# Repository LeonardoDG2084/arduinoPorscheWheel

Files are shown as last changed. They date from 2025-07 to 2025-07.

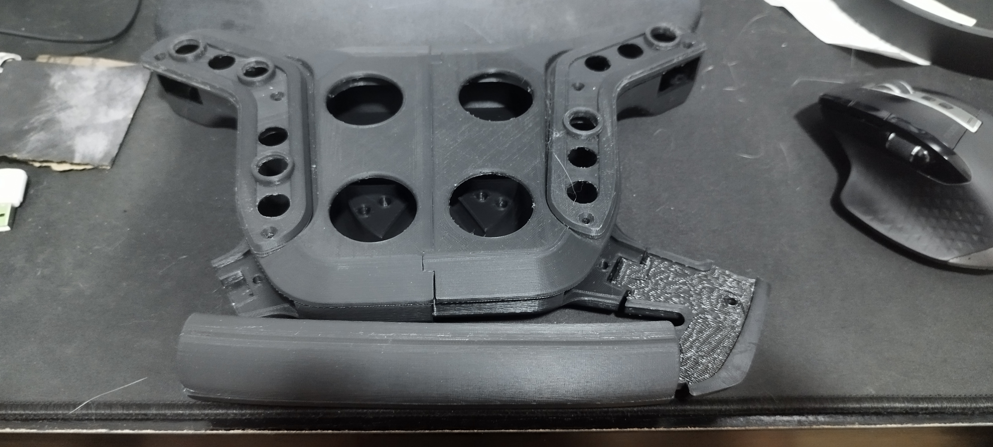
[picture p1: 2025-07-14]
imgs/IMG_20241227_091950.jpg

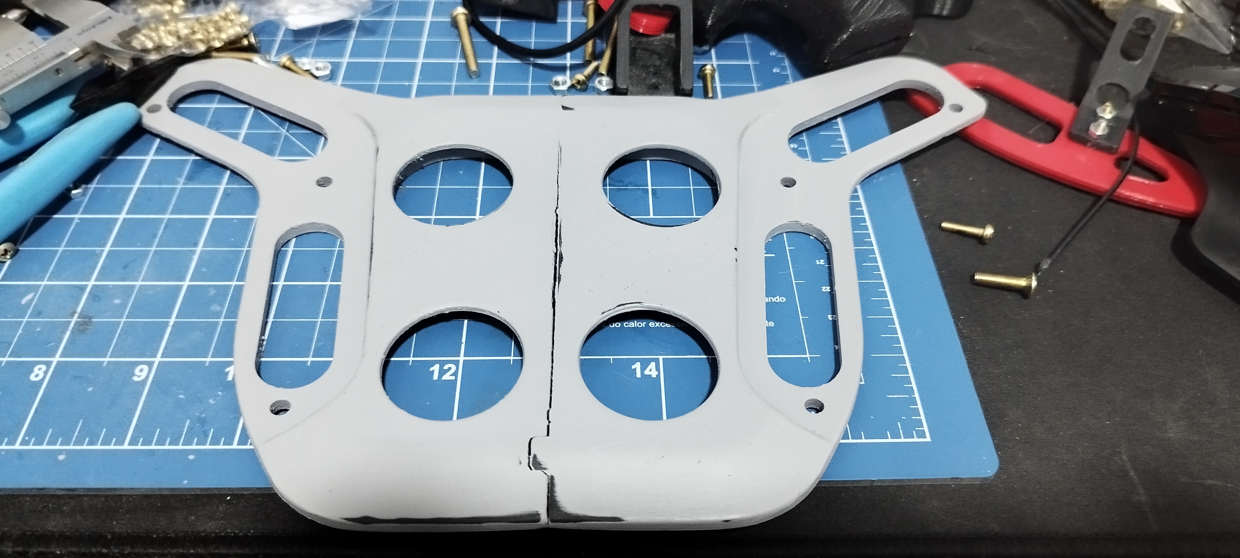
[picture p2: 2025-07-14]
imgs/IMG_20250108_130740.jpg

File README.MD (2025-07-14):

# Introdução

Esse repositorio foi criado para quem deseja reproduzir o projeto de volante do porsche 992 hospedado nesse !(link)https://www.printables.com/model/337684-turn-911-gt3-r-2023-diy-sim-racing-steering-wheel, ao criar esse volante algumas coisas não estavam 100% presentes e também o link do discord para tirar duvidas parece que foi desativado, outra dificuldade foi não ir pelo caminho de mandar fazer a PCB, o que iria encaresser demais o valor do volante, que no momento que fiz gastei em torno de R$500,00. Para esse projeto é necessario uma impressora 3d e algumas ferramentas que vou listar aqui, então antes de decidir reproduzir esse volante verifique se consiga ter acesso a ferramentas e componentes que serão necessários.

Esse foi o primeiro volante que fiz e também primeiro contato com muita das coisas que precisei fazer como pintura, eletronica, arduino, etc, Logo você pode identificar algumas decisões erradas empregadas aqui, se tiver algo a acrescentar faça um comentario ou issue ou PR, se tiver familiarizado com o GitHUB.

Diferenças entre o projeto original e o que acabei fazendo, no lugar dos rotacionadores centrais que possuem posições especificas eu optei por utilizar encoders rotativos comuns o que faz reduzir as opções de configurações, mas o volante acabou ficando com 26 botões, acredito que seja o suficiente para configurar tudo durante a corrida. Volante não possui quaisquer LED, prefiri dar prioridade aos botões.

# Caracteristicas do volante

- 2 - Paddle Switchs
- 1 - Embreagem (potenciomento)
- 14 - Botões (12 Frontais e 2 Traseiros)
- 5 - Encoders rotativos 
- 1 - Joystick Analogico

# Materiais e Valores

 - Fusion360
    - Licença para uso pessoal.
- Impressora 3d 
 - Utilizei uma Ender 3 V1 com bico de 0.4 e 1Kg de filamento de qualquer cor eu utilizei PLA (R$100,00)
 - Uma chapa de aluminio de 3mm 20x30cm (R$35,00)
    - Serra tico-tico
    - Laminas para aluminio que cortem aluminio de 3m possam fazer contorno. 
    - Sugestão de serras: Bosh T118EOF ou Starrett BU214S (R$50,00)
- Lixas (150,250, 400 e 600) (R$10,00)
- Spray 
    - Primer (R$25,00)
    - Preto (R$25,00)
    - Cinza Metalico (R$25,00)
    - Verniz (R$25,00)
- Parafusos e Porcas
  - M3 (R$5,00)
  - M4 (R$5,00)
- Switchs (R$10,00)
- Insert metalico de rosca
    - M3 (R$30,00)
    - M4 (R$30,00)
- Botões
    - Tactil de 12mm (R$30,00)
- Arduino Pro micro (R$50,00)
- Imã 
    - 10x3mm (R$25,00)
- Encoders Rotativos (R$20,00)
- Potenciomento 10k (R$3,00)
- Multiplexador 16 canais CD74HC4067 (R$20,00)
- Cabos Jumpers para prototipo e euilização posterior. (R$30,00)
- Ferro de Solda (R$60,00)
- Estanho (R$15,00)
- Joystick Analogico para arduino (R$20,00)
- Cabo USB micro espiral
- Plugue macho e femea GX2 de 4 vias (R$13,00)
- Multimetro 

# Impressão 3d

Não tem muito segredo para a impressão 3d, a orientação das peças estão presentes no PDF dentro desse repositorio, unica dica é referente a altura da camada, se o seu fatiador possuir a funcionalidade de altura variavel, reduza a altura da camada em lugares curvos para reduzir o tempo de lixamento, é melhor a impressora trabalhar do que você!.

# Aro em Aço (Opicional)

# Lixamento e Pintura

# Soldagem

# Eletronica

Nesse projeto utilizei todas as portas do Arduino e foi necessário um multiplexador para conseguir colocar os 26 botões.
O esquema de Fios estão presentes nesse repositorio.

# Embreagem

No projeto não da detalhes de como fazer a embreagem, então recorri a um pojeto de embreagem pronto e adaptei ao furo do volante, os arquivos podem ser encontrados nesse repositorio

# Joystick Analogico

# Knobs

Os knobs utilizados nesse projeto originalmente achei pequenos e acabei optando por fazer novos utilizando esse projeto: !(link)https://www.printables.com/model/580299-ultimate-diy-replacement-knob-pack-for-samsung-sme/files

Acabei utilizando o modelo 7, para editar ele de acordo com as dimensões do furo você vai precisar do Fusion360, nesse !(video)https://www.youtube.com/watch?v=VST1j0NKjeQ ele mostra como, nele vc consegue dimensionar para caber nos furos da tampa do volante.

# Montagem

# Grips (empunhaduras)

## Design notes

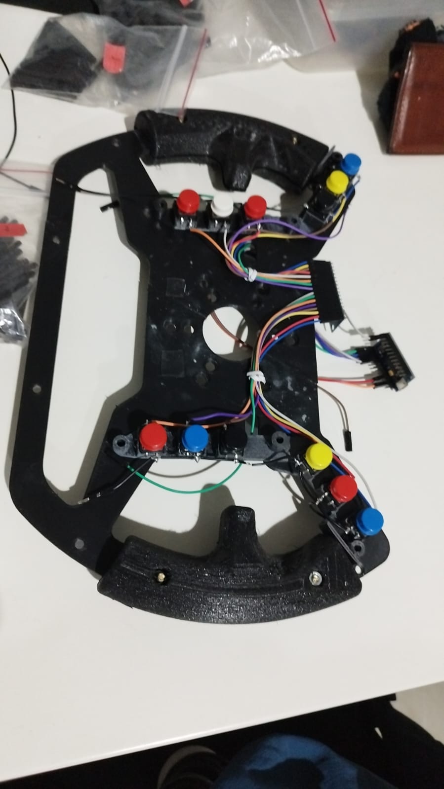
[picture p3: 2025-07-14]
imgs/Imagem do WhatsApp de 2025-01-16 à(s) 18.56.38_65e9340a.jpg

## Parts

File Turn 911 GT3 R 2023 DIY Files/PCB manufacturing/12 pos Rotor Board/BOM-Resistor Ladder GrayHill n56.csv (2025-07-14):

Comment | Designator | Footprint | LCSC
R_Small | R1,R10,R11,R2,R3,R4,R5,R6,R7,R8,R9 | R_0402_1005Metric | C11702

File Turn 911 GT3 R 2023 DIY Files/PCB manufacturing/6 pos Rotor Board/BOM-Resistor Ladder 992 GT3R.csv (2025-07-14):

Comment | Designator | Footprint | LCSC
R_Small | R12,R13,R14,R15,R16,R17,R18 | R_0402_1005Metric | C11702

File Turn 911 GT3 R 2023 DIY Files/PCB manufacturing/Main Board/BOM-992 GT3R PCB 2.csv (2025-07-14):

Comment | Designator | Footprint | LCSC
LED | D1,D10,D11,D12,D13,D14,D15,D16,D17,D18,D19,D2,D20,D21,D22,D23,D24,D25,D26,D27,D28,D29,D3,D30,D31,D32,D33,D34,D35,D36,D37,D38,D39,D4,D40,D41,D42,D43,D44,D45,D46,D47,D48,D49,D5,D50,D51,D52,D6,D7,D8,D9 | LED_0805_2012Metric | C110099
10NF | C1,C2,C3,C4 | C_0805_2012Metric | C1710

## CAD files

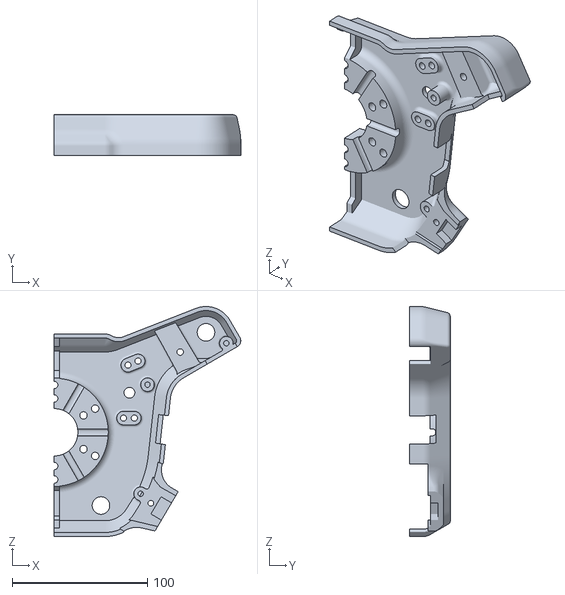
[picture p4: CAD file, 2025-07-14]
Turn 911 GT3 R 2023 DIY Files/3D Pritning/FDM Pritning/Main Shell Right.stl
138.1 x 30.0 x 170.3

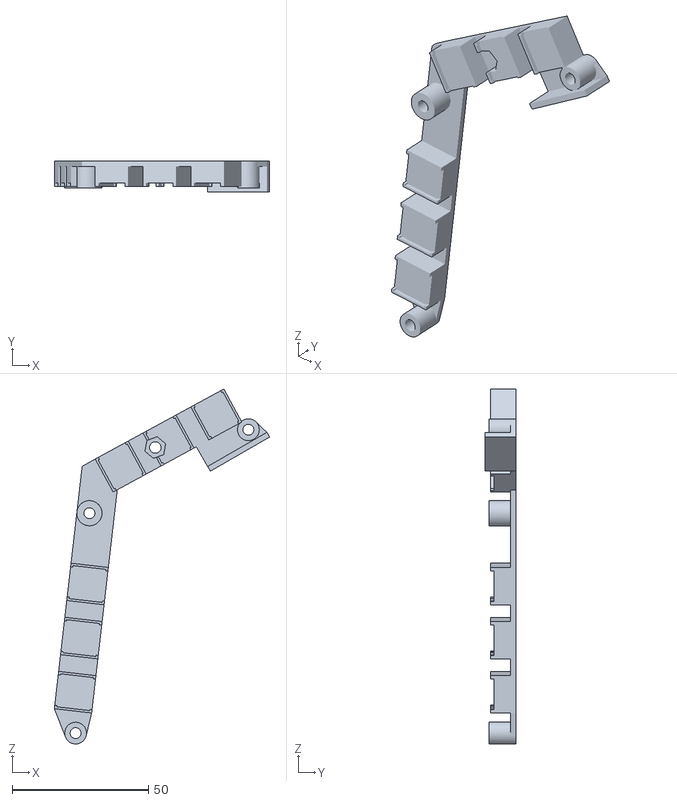
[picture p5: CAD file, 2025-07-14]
custom/NonPCB-button-holder-right.stl
79.1 x 11.5 x 130.4

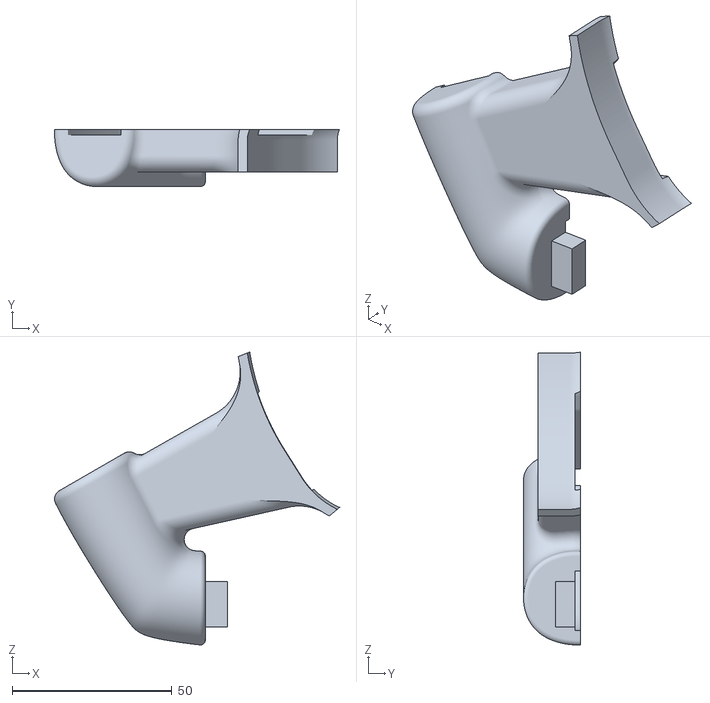
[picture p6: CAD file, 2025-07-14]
Turn 911 GT3 R 2023 DIY Files/3D Pritning/3D Printing Service/PA-12 Nylon/Front handel Left MJF.stl
89.1 x 17.8 x 91.6

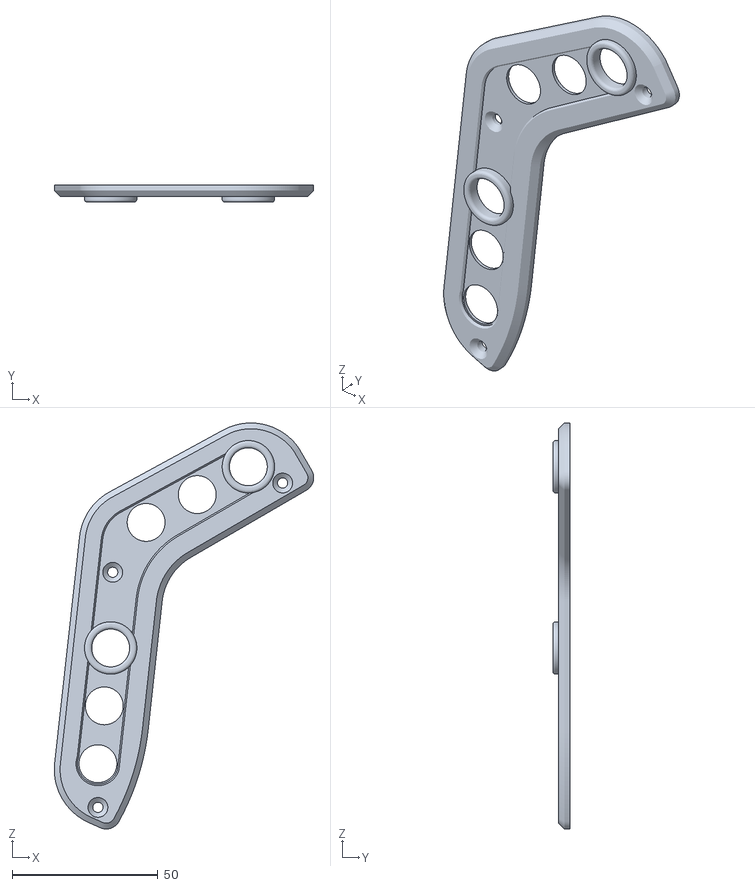
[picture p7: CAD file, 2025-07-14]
Turn 911 GT3 R 2023 DIY Files/3D Pritning/3D Printing Service/Resin Black/Button Guard Right.stl
89.1 x 6.00 x 139.5

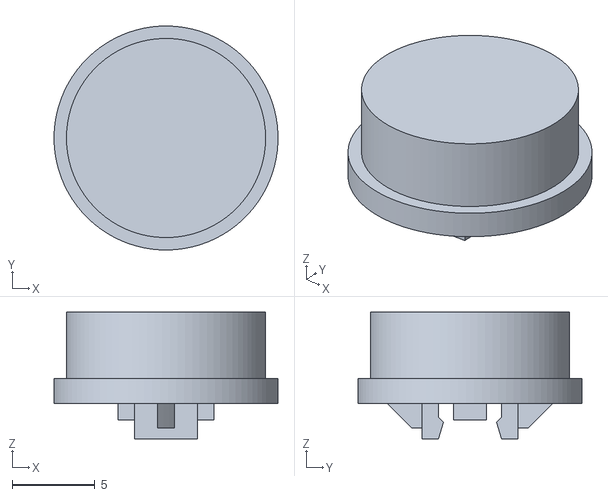
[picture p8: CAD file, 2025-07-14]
Turn 911 GT3 R 2023 DIY Files/3D Pritning/3D Printing Service/Resin White/Button Cap 12mm.stl
13.5 x 13.5 x 7.65

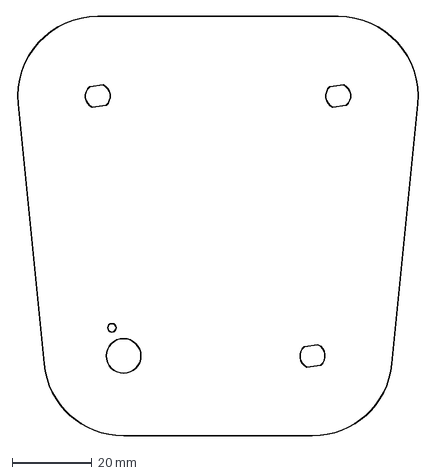
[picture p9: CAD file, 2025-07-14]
Turn 911 GT3 R 2023 DIY Files/Acrylic Sheet/Acrylic Sheet DXF.dxf
101.1 x 105.1 mm

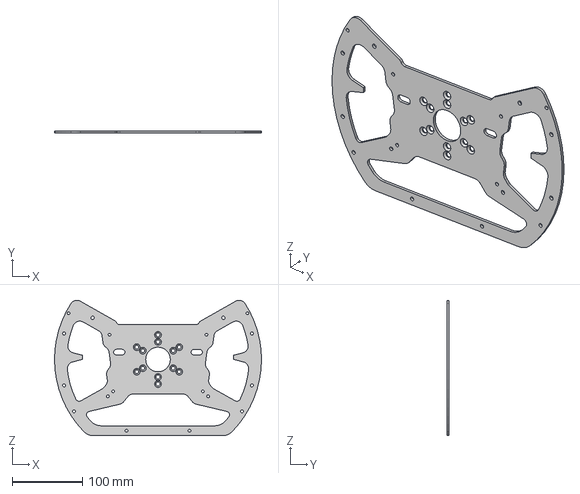
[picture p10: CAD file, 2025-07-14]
Turn 911 GT3 R 2023 DIY Files/Core Plate and Shifters/Core Plate.step
295.0 x 3.00 x 193.0 mm

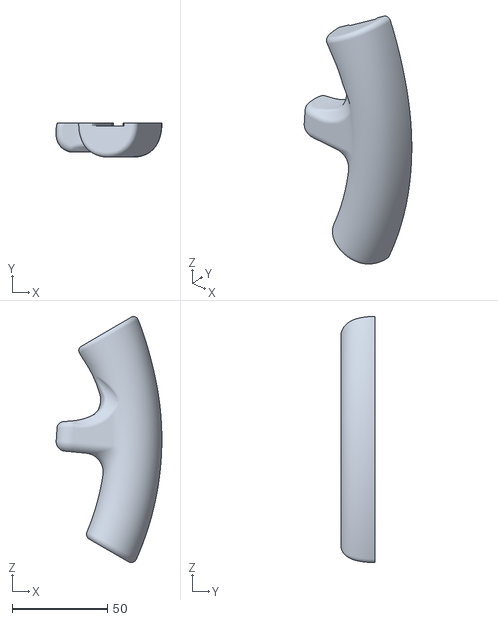
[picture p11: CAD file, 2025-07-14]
Turn 911 GT3 R 2023 DIY Files/Grips/Insert Grips Softtuch/Right Front grip Inserts Softtuch.stl
55.4 x 18.0 x 128.9

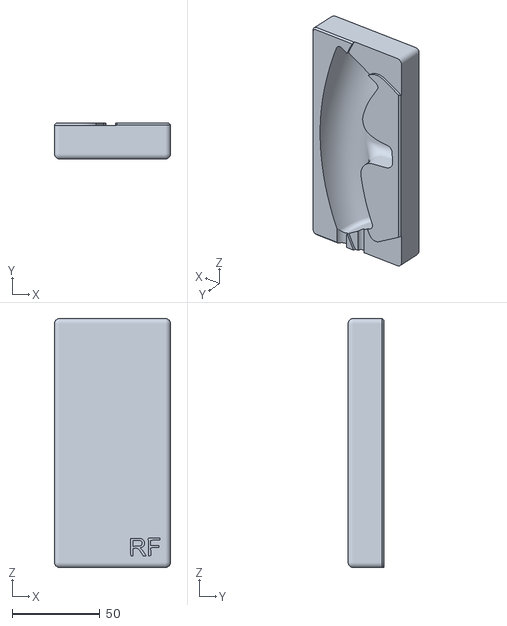
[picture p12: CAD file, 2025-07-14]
Turn 911 GT3 R 2023 DIY Files/Grips/Molded Grips/RF Mold.stl
66.3 x 20.5 x 142.1

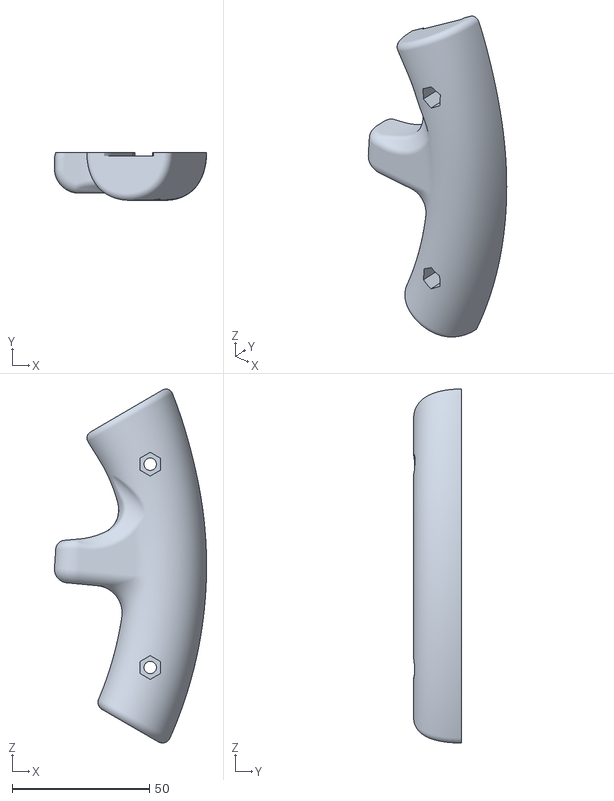
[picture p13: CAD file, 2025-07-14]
Turn 911 GT3 R 2023 DIY Files/Grips/Printed Gap/Grip Gap Right Front.stl
55.4 x 17.3 x 128.8

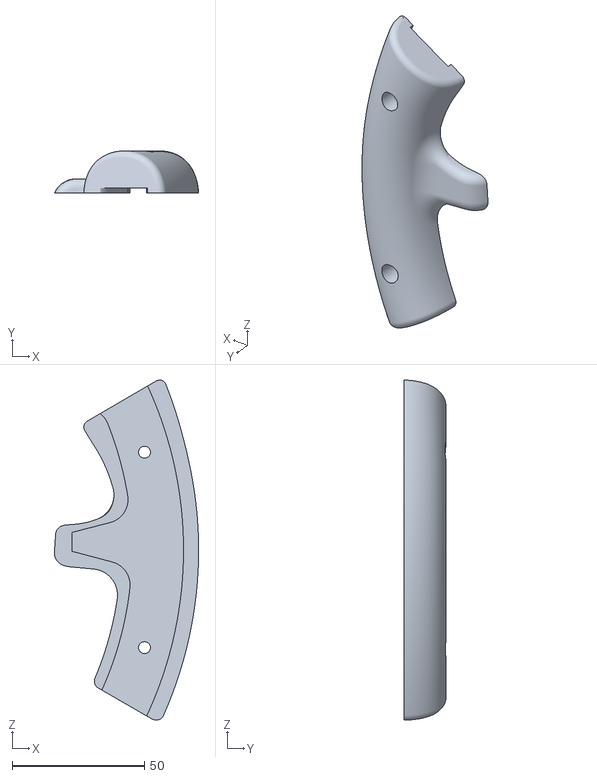
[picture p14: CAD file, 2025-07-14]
Turn 911 GT3 R 2023 DIY Files/Grips/Printed No Cap/Grip NoGap Right Back.stl
54.6 x 16.0 x 128.7

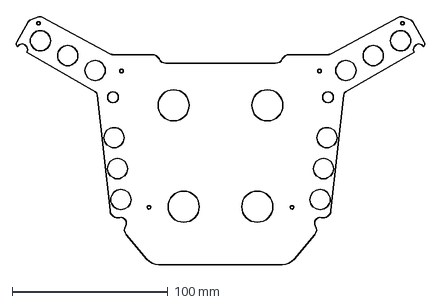
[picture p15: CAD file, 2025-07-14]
Turn 911 GT3 R 2023 DIY Files/PCB Files KiCad/PCB outline.dxf
262.6 x 159.4 mm

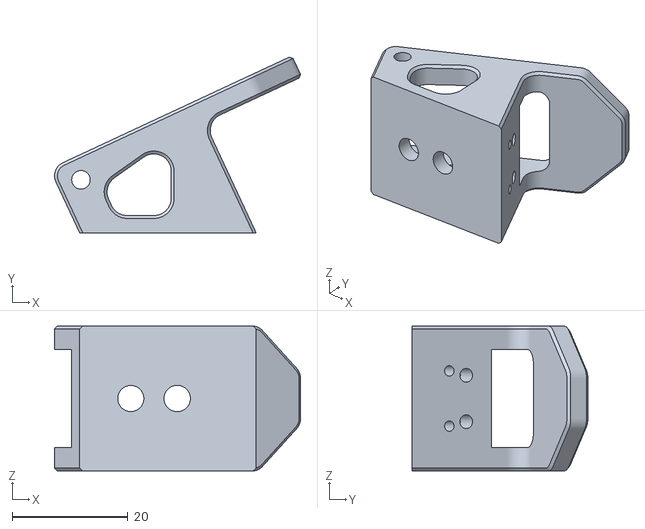
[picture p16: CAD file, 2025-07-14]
Turn 911 GT3 R 2023 DIY Files/Shifters/3D Pritning/Shifter Body v2_4p.stl
42.5 x 30.3 x 25.0

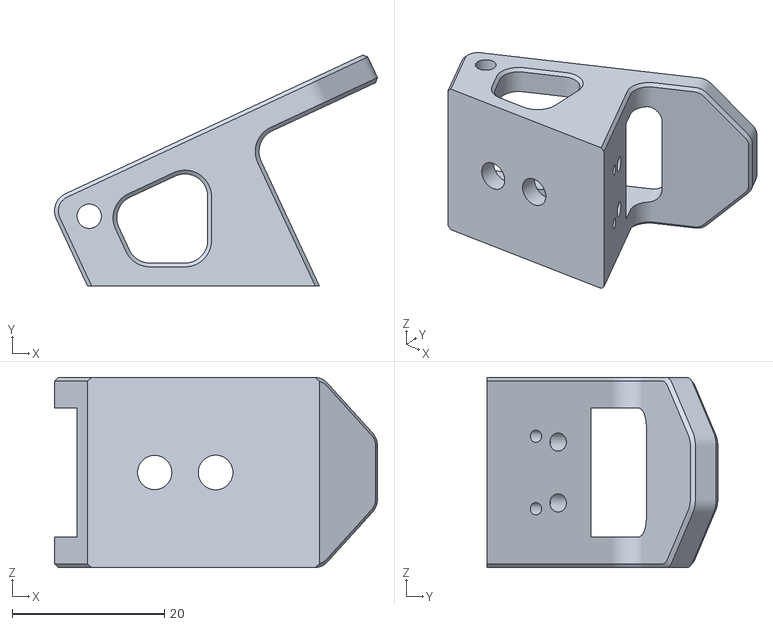
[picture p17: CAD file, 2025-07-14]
Turn 911 GT3 R 2023 DIY Files/Shifters/CNC/Shifter Body V2_3c.stl
42.5 x 30.3 x 25.0

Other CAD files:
Turn 911 GT3 R 2023 DIY Files/3D Pritning/FDM Pritning/Main Shell Left.stl
custom/top-knobs-and-joystick.stl
Turn 911 GT3 R 2023 DIY Files/3D Pritning/3D Printing Service/PA-12 Nylon/Handel Mid Front MJF.stl
Turn 911 GT3 R 2023 DIY Files/3D Pritning/3D Printing Service/Resin Black/Thumb Rotor.stl
Turn 911 GT3 R 2023 DIY Files/3D Pritning/3D Printing Service/PA-12 Nylon/Front Lid MJF.stl
Turn 911 GT3 R 2023 DIY Files/3D Pritning/3D Printing Service/PA-12 Nylon/Front handel Right MJF.stl
Turn 911 GT3 R 2023 DIY Files/3D Pritning/3D Printing Service/PA-12 Nylon/Handel Mid Back MJF.stl
Turn 911 GT3 R 2023 DIY Files/3D Pritning/3D Printing Service/Resin Black/12p Rotor Knob.stl
Turn 911 GT3 R 2023 DIY Files/3D Pritning/3D Printing Service/Resin Black/6p Rotor Knob.stl
Turn 911 GT3 R 2023 DIY Files/3D Pritning/3D Printing Service/Resin Black/Button Guard Left.stl
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

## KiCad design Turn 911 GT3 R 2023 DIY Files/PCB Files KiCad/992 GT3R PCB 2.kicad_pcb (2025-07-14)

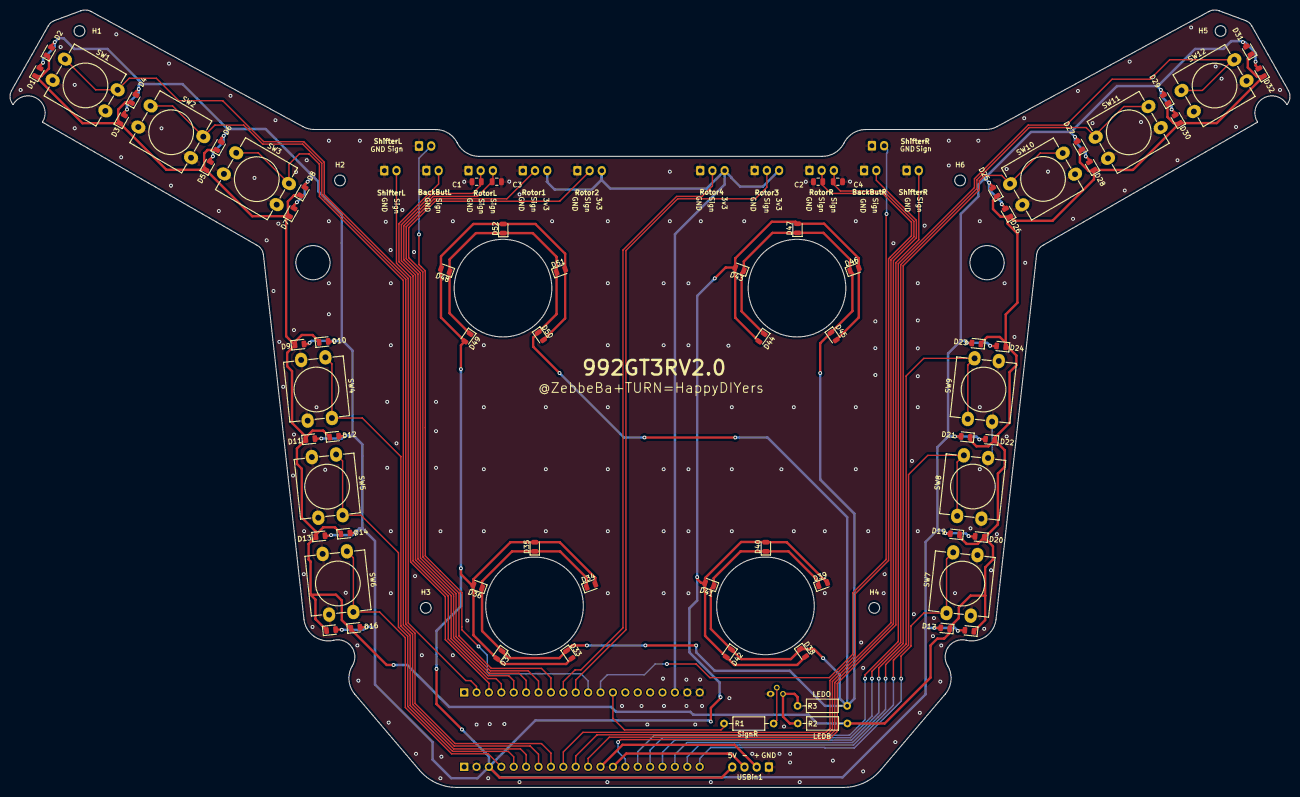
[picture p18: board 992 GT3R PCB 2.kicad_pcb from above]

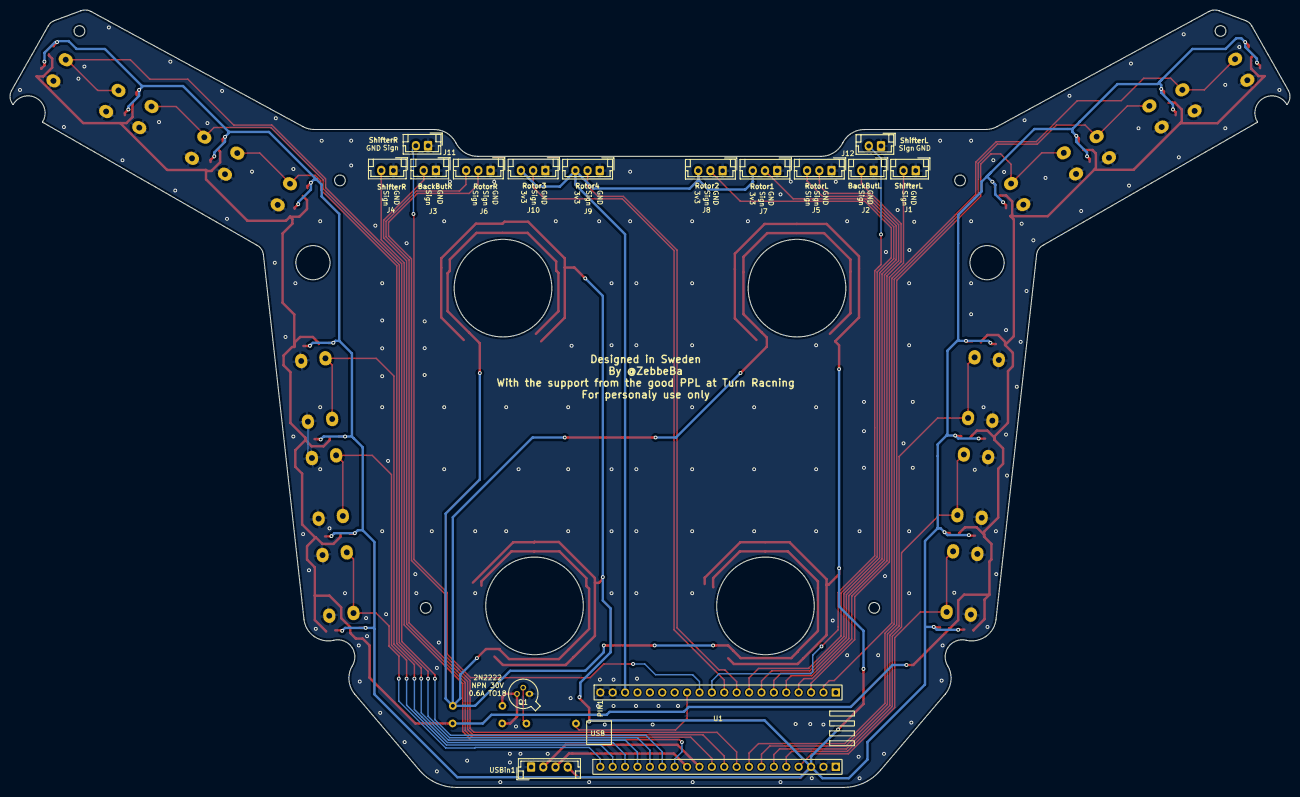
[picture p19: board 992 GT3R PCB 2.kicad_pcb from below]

Board: 2 copper layers, 262.2 x 159.3 mm, 92 parts (15 on the bottom side), 36 nets.

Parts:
C1, C2, C3, C4: 10NF; C_0805_2012Metric
D1, D2, D3, D4, D5, D6, D7, D8, D9, D10, D11, D12, D13, D14, D15, D16, D17, D18, D19, D20, D21, D22, D23, D24, D25, D26, D27, D28, D29, D30, D31, D32, D33, D34, D35, D36, D37, D38, D39, D40, D41, D42, D43, D44, D45, D46, D47, D48, D49, D50, D51, D52: LED; LED_0805_2012Metric
H1, H2, H3, H4, H5, H6: MountingHole; MountingHole_2.2mm_M2
J1, J2, J3, J4, J11, J12: Conn_01x02_Female; JST_EH_B2B-EH-A_1x02_P2.50mm_Vertical
J5, J6, J7, J8, J9, J10: Conn_01x03_Female; JST_EH_B3B-EH-A_1x03_P2.50mm_Vertical
Q1: 2N2219; TO-18-3
R1: 220R; R_Axial_DIN0207_L6.3mm_D2.5mm_P10.16mm_Horizontal
R2: 47R; R_Axial_DIN0207_L6.3mm_D2.5mm_P10.16mm_Horizontal
R3: 100R; R_Axial_DIN0207_L6.3mm_D2.5mm_P10.16mm_Horizontal
SW1, SW2, SW3, SW4, SW5, SW6, SW7, SW8, SW9, SW10, SW11, SW12: SW_Push_Dual; SW_PUSH-12mm_Wuerth-430476085716
U1: Blue_Pill_STM32F103C8T6
USBin1: Conn_01x04_Female; JST_EH_B4B-EH-A_1x04_P2.50mm_Vertical

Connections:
B0LEDCONTROL: R1.1, U1.8 (B0)
GND: C1.2, C2.2, C3.2, C4.2, J1.1, J2.1, J3.1, J4.1, J5.1, J6.1, J7.1, J8.1, J9.1, J10.1, J11.1, J12.1, Q1.1 (E), SW1.2, SW2.2, SW3.2, SW4.2, SW5.2, SW6.2, SW7.2, SW8.2, SW9.2, SW10.2, SW11.2, SW12.2, U1.1 (GND), U1.2 (GND), U1.39 (GND), USBin1.1
LEDPwr: D1.2 (A), D2.2 (A), D3.2 (A), D4.2 (A), D5.2 (A), D6.2 (A), D7.2 (A), D8.2 (A), D9.2 (A), D10.2 (A), D11.2 (A), D12.2 (A), D13.2 (A), D14.2 (A), D15.2 (A), D16.2 (A), D17.2 (A), D18.2 (A), D19.2 (A), D20.2 (A), D21.2 (A), D22.2 (A), D23.2 (A), D24.2 (A), D25.2 (A), D26.2 (A), D27.2 (A), D28.2 (A), D29.2 (A), D30.2 (A), D31.2 (A), D32.2 (A), D33.2 (A), D34.2 (A), D35.2 (A), D36.2 (A), D37.2 (A), D38.2 (A), D39.2 (A), D40.2 (A), D41.2 (A), D42.2 (A), D43.2 (A), D44.2 (A), D45.2 (A), D46.2 (A), D47.2 (A), D48.2 (A), D49.2 (A), D50.2 (A), D51.2 (A), D52.2 (A), U1.38 (5V), USBin1.4
unnamed: C1.1, J5.2, U1.16 (A0)
unnamed: C2.1, J6.2, U1.32 (B4)
unnamed: C3.1, J5.3, U1.15 (A1)
unnamed: C4.1, J6.3, U1.31 (B3)
unnamed: D1.1 (K), D2.1 (K), D3.1 (K), D4.1 (K), D5.1 (K), D6.1 (K), D7.1 (K), D8.1 (K), D9.1 (K), D10.1 (K), D11.1 (K), D12.1 (K), D13.1 (K), D14.1 (K), D15.1 (K), D16.1 (K), D17.1 (K), D18.1 (K), D19.1 (K), D20.1 (K), D21.1 (K), D22.1 (K), D23.1 (K), D24.1 (K), D25.1 (K), D26.1 (K), D27.1 (K), D28.1 (K), D29.1 (K), D30.1 (K), D31.1 (K), D32.1 (K), R2.2
unnamed: D33.1 (K), D34.1 (K), D35.1 (K), D36.1 (K), D37.1 (K), D38.1 (K), D39.1 (K), D40.1 (K), D41.1 (K), D42.1 (K), D43.1 (K), D44.1 (K), D45.1 (K), D46.1 (K), D47.1 (K), D48.1 (K), D49.1 (K), D50.1 (K), D51.1 (K), D52.1 (K), R3.2
unnamed: J1.2, U1.18 (C14)
unnamed: J2.2, U1.17 (C15)
unnamed: J3.2, U1.30 (A15)
unnamed: J4.2, U1.27 (A10)
unnamed: J11.2, U1.9 (A7)
unnamed: J12.2, U1.10 (A6)
unnamed: Q1.2 (B), R1.2
unnamed: Q1.3 (C), R2.1, R3.1
unnamed: SW1.1, U1.19 (C13)
unnamed: SW2.1, U1.33 (B5)
unnamed: SW3.1, U1.34 (B6)
unnamed: SW4.1, U1.35 (B7)
unnamed: SW5.1, U1.36 (B8)
unnamed: SW6.1, U1.37 (B9)
unnamed: SW7.1, U1.21 (B12)
unnamed: SW8.1, U1.22 (B13)
unnamed: SW9.1, U1.23 (B14)
unnamed: SW10.1, U1.24 (B15)
unnamed: SW11.1, U1.25 (A8)
unnamed: SW12.1, U1.26 (A9)
Rotor1Sign: J7.2, U1.14 (A2)
Rotor2Sign: J8.2, U1.13 (A3)
Rotor3Sign: J9.2, U1.12 (A4)
Rotor3v3: J7.3, J8.3, J9.3, J10.3, U1.3 (3v3)
Rotor4Sign: J10.2, U1.11 (A5)
UDBD+: U1.29 (A12), USBin1.2
USBD-: U1.28 (A11), USBin1.3

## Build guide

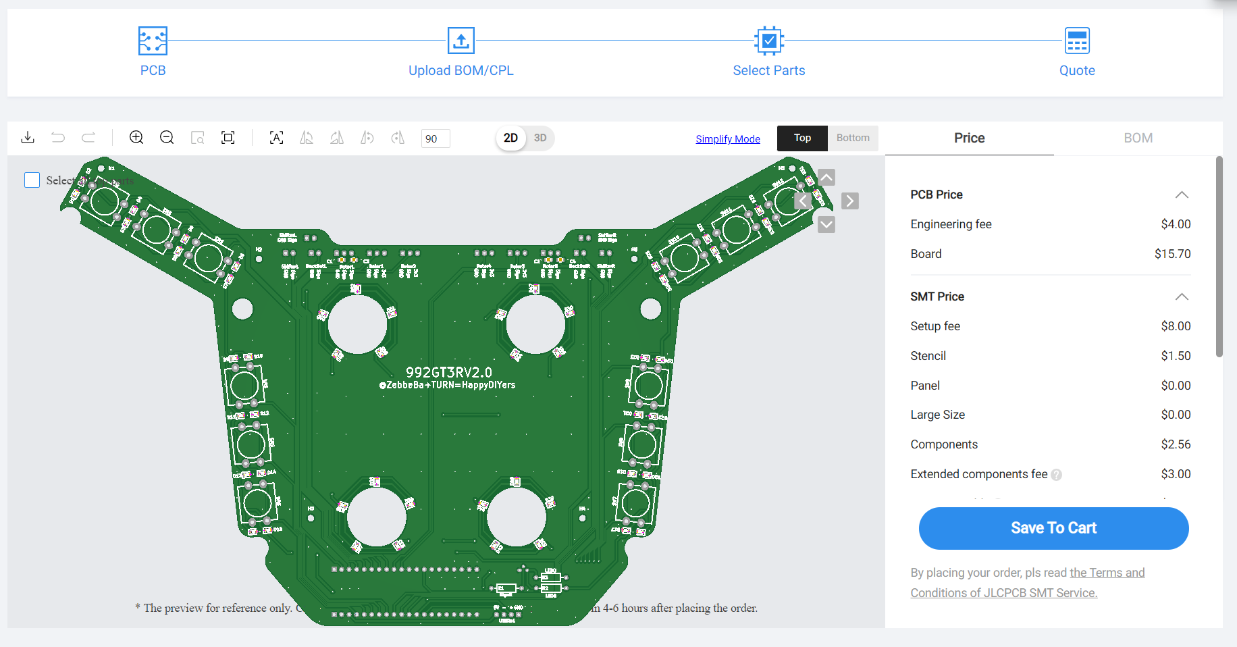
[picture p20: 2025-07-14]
Turn 911 GT3 R 2023 DIY Files/PCB manufacturing/Page 4 Config JLC.PNG

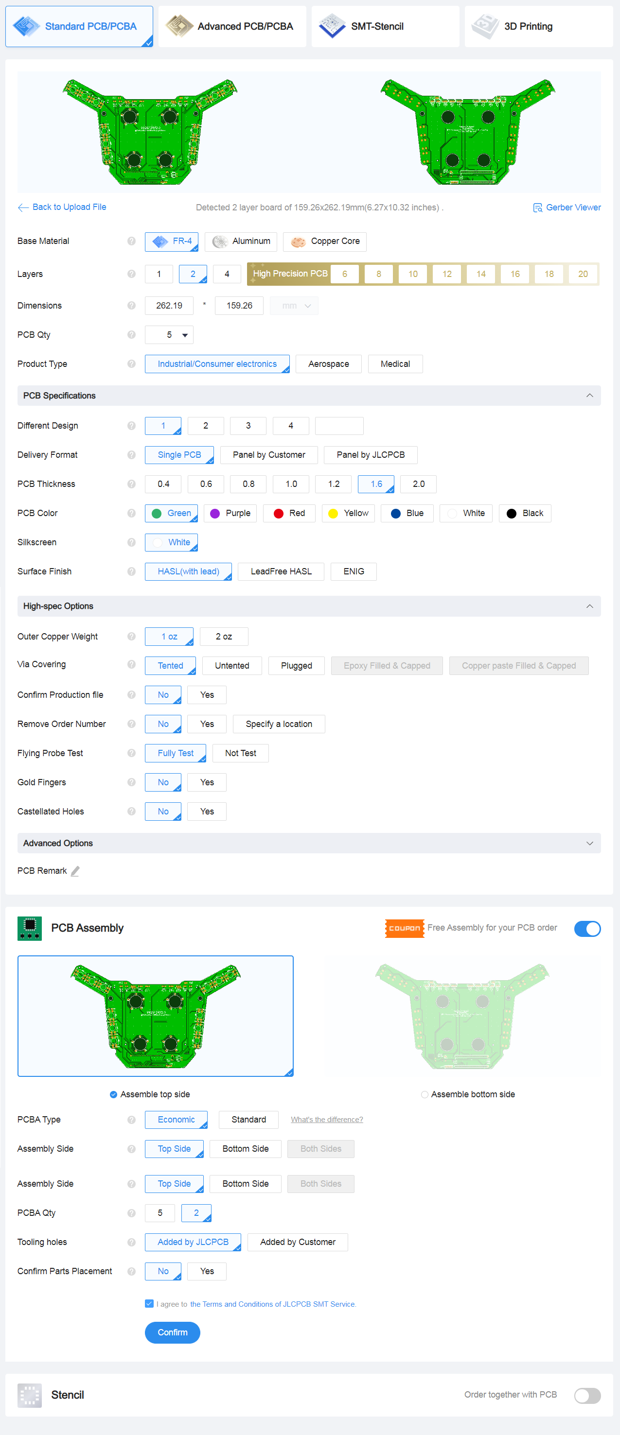
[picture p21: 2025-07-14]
Turn 911 GT3 R 2023 DIY Files/PCB manufacturing/Page 1 Config JLC.png

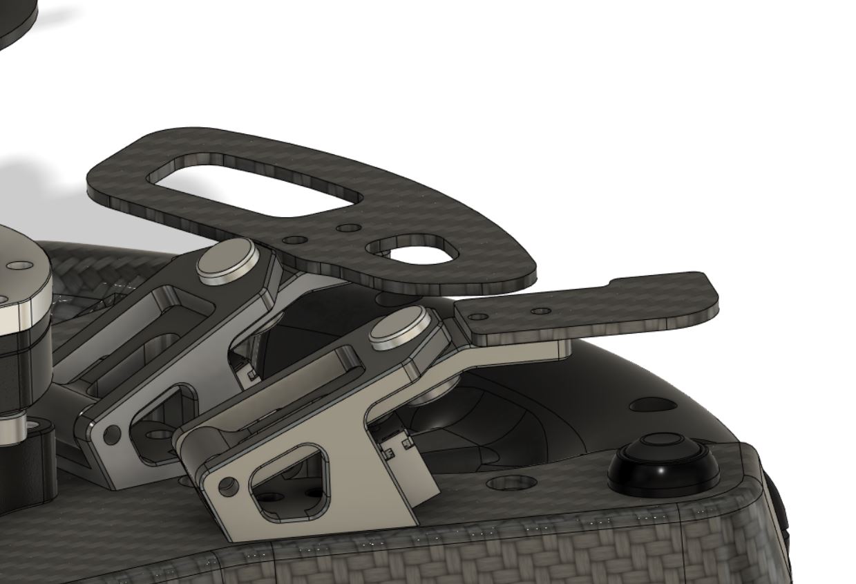
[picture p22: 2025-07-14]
Turn 911 GT3 R 2023 DIY Files/Shifters/CNC/Assemblyviwe.JPG

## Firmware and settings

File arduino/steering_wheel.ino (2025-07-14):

/*
12 botões frontais
04 botões traseiros (2 Paddles + 2 botões)
1 embreagem (potenciometro)
5 encoders (10 funções) -
--------------------
Matriz de botões
14 botões - C15 - C0

---------------------
3/4           - 1 - encoder  PCINT2
2/5           - 2 - encoder  PCINT2
0/6           - 3 - encoder  PCINT2
1/7           - 4 - encoder  PCINT2
A3(21)/A0(18) - 5 - encoder  PCINT1
----------------------
10 - signal - Buttons
16 - S0
15 - S1
14 - S2
09 - S3
-----------------------
A1 - VRx (Analog)
A2 - VRy (Analog)
A8(8) - Potenciometer (clutch)

Grupo de interrupções por porta
# PCINT0 - D8, D9, D10, D11, D12, D13,
# PCINT1 - A0, A1, A2, A3, A4, A5
# PCINT2 - D0, D1, D2, D3, D4, D5, D6, D7

*/


#include <Joystick.h>
#include <Arduino.h>
#include <BasicEncoder.h>
#include <TimerOne.h>

// Comando analogico
#define joyX A1
#define joyY A2
const int deadzone = 30;  // Zona morta para evitar tremores
// Potenciometro (Clutch)
#define joyRZ A3

// Botões do multiplexador
#define SIG 10
#define S0 16
#define S1 15
#define S2 14
#define S3 9
#define NUM_BUTTONS 16

// Inicialização
int xAxis_ = 0;
int yAxis_ = 0;
int rzAxis_ = 0;


// Encoders
BasicEncoder encoder1(3, 4);  // Direito           // 1
BasicEncoder encoder2(7, 18); // Esquerdo          // 2
BasicEncoder encoder3(0, 1);  // Superior Direito  // 5
BasicEncoder encoder4(2, 5);  // Inferior Esquerdo // 4
BasicEncoder encoder5(8, 6);  // Inferior Direito  // 3

void timer_service() {
  encoder1.service();
  encoder2.service();
  encoder3.service();
  encoder4.service();
  encoder5.service();
}

// Instancia do Joystick
Joystick_ Joystick(JOYSTICK_DEFAULT_REPORT_ID,JOYSTICK_TYPE_GAMEPAD,
  25, 1,                                            // Numero de botões, Hat Switch 
  false, false, false,                              // X,Y and Z Eixos 
  false, false, true,                              // Rx, Ry, Rz
  false, false,                                     // Rudder, throttle  
  false, false, false                                // Accelerator, Brake and steering
);

void setup() {
  //Serial.begin(115200);
  Timer1.initialize(1000);
  Timer1.attachInterrupt(timer_service);
  Joystick.begin(); 

  //Comando analogico
  Joystick.setXAxisRange(1023, 0);
  Joystick.setYAxisRange(1023, 0);

  // Multiplexador
  pinMode(S0,OUTPUT);
  pinMode(S1,OUTPUT);
  pinMode(S2,OUTPUT);
  pinMode(S3,OUTPUT);
  pinMode(SIG,INPUT_PULLUP);
}

void loop() {

  int encoder_change1 = encoder1.get_change();
  int encoder_change2 = encoder2.get_change();
  int encoder_change3 = encoder3.get_change();
  int encoder_change4 = encoder4.get_change();
  int encoder_change5 = encoder5.get_change();
  if (encoder_change1) {
    if (encoder_change1 == -1) {
      //Serial.println("Atrás 1");
      Joystick.setButton(0, true);
      delay(50);
      Joystick.setButton(0, false);
    }
    else {
      //Serial.println("Frente 1");
      Joystick.setButton(1, true); 
      delay(50);
      Joystick.setButton(1, false); 
    }
}
  if (encoder_change2) {
    if (encoder_change2 == -1) {
      //Serial.println("Atrás 2");
      Joystick.setButton(2, true);
      delay(50);
      Joystick.setButton(2, false);
    }
    else {
      //Serial.println("Frente 2");
      Joystick.setButton(3, true); 
      delay(50);
      Joystick.setButton(3, false);
    }    
  }
  if (encoder_change3) {
    if (encoder_change3 == -1) {
      //Serial.println("Atrás 3");
      Joystick.setButton(4, true);
      delay(50);
      Joystick.setButton(4, false);
    }
    else {
      //Serial.println("Frente 3");
      Joystick.setButton(5, true); 
      delay(50);
      Joystick.setButton(5, false);
    }    
  }
  if (encoder_change4) {
    if (encoder_change4 == -1) {
      //Serial.println("Atrás 4");
      Joystick.setButton(6, true);
      delay(50);
      Joystick.setButton(6, false);
    }
    else {
      //Serial.println("Frente 4");
      Joystick.setButton(7, true); 
      delay(50);
      Joystick.setButton(7, false); 
    }    
  }
  if (encoder_change5) {
    if (encoder_change5 == -1) {
      //Serial.println("Atrás 5");
      Joystick.setButton(8, true);
      delay(50);
      Joystick.setButton(8, false);       
    }
    else {
      //Serial.println("Frente 5");
      Joystick.setButton(9, true); 
      delay(50);
      Joystick.setButton(9, false); 
    }    
  }

  // Comando analogico Axis X e Y
  xAxis_ = analogRead(joyX) - 512;
  yAxis_ = analogRead(joyY) - 512;
  int hatState = -1;


  //Debug Analogico
  
  //Eixo X
  //Joystick.setXAxis(xAxis_);
  //Debug
  Serial.print("X: ");
  Serial.println(xAxis_);
  //Eixo Y
  //Joystick.setYAxis(yAxis_);
  //Debug
  Serial.print("y: ");
  Serial.println(yAxis_);

  // Analogico
  if (yAxis_ > deadzone) hatState = 180;   // Cima
  else if (yAxis_ < -deadzone) hatState = 0; // Baixo
  else if (xAxis_ > deadzone) hatState = 90;  // Direita
  else if (xAxis_ < -deadzone) hatState = 270; // Esquerda
  Joystick.setHatSwitch(0, hatState); // Envia o valor do Hat Switch

  // Potentiometer 10k 
  rzAxis_ = analogRead(joyRZ);
  Joystick.setRzAxis(rzAxis_);
  
  //Debug
  //Serial.println(rzAxis_);

  // Loop de todos os botões do multiplexador
  for (int button = 0; button < NUM_BUTTONS; button++) {
    // Seleciona o canal no multiplexador
    selectMuxChannel(button);
    // Lê o estado do botão
    int buttonState = digitalRead(SIG);
    // O multiplexador retorna LOW quando o botão está pressionado
    bool pressed = (buttonState == LOW);
    // Atualiza o estado do botão no joystick
    Joystick.setButton(button+9, pressed);
    //Debug
    //Serial.print("Botão: ");
    //Serial.println(button+10);
  }
}

void selectMuxChannel(int channel) {
  digitalWrite(S0, channel & 0x01); // LSB
  digitalWrite(S1, channel & 0x02);
  digitalWrite(S2, channel & 0x04);
  digitalWrite(S3, channel & 0x08); // MSB
}
